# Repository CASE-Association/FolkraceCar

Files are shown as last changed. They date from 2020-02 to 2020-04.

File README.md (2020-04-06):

# CASE Folkrace Car - laZEr

## The 2020 Folkrace car project
 A car developed for the main focus of evaluationg, methos for producing a fun and educational car for the Robot SM Folkrace class.
 These are the main topics:
- Navigation
- Mapping/ localisation
- Electric design
- Cassis design
- Weight optimization

## Project Structure

## Placeholder

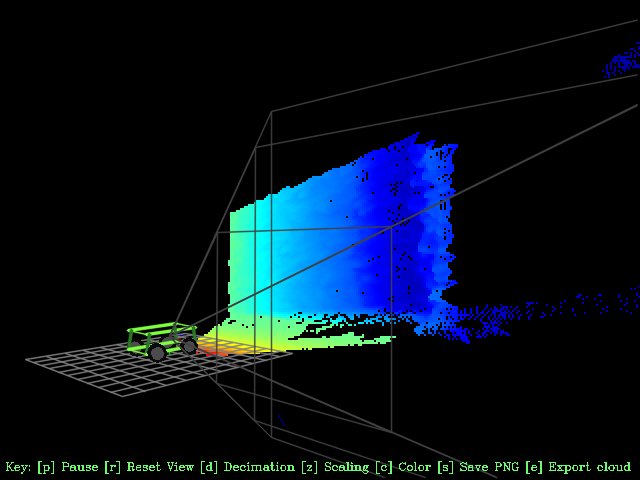
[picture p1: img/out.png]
out


## System overview

## How do you use it?

## How does it work?

## Development

## Contributors

## License

Distributed under the MIT license. See ``LICENSE`` for more information.

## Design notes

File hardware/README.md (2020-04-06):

# Hardware - CASE Folkrace Car

This document describes a general overview of the system hardware used.

### Preliminary rendering of electronics

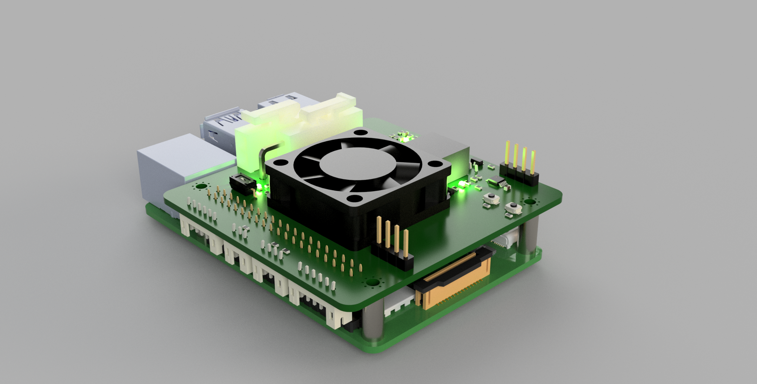
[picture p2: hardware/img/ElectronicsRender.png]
Electronics Render


### Todo hardware
* Add connector for hall effect sensor (should include pull-up)
* Connector for RP4: [Adafruit 2223](https://www.adafruit.com/product/2223) [(from Mouser)](https://www.mouser.se/ProductDetail/Adafruit/2223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)
* Change one TOF connector to angled version - currently interferes with HDMI connectors on RP4.

### Mistakes on REV 1 of PCB

* VBUS bulk decoupling capacitors share single via for ground return path - will probably cause to much inductance. Maybe add cap directly over BATT+ and GND on pcb underside.

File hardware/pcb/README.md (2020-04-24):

## Notes for Folkrace PCB

### Bring up notes for REV 1-2

* eFuse does not work consistently - two have been broken - unclear why

#### Changes for next rev

* Add way to connect external 5V (protection for DC/DC)
* On off for 3V3 (complete rail)
* Move to edge-mounted buttons
* Check real width of screen (38 mm length)
* Reconnect fault LED to not be on when off
* Change to better switch for on/off operation
* Transient protection and possibly reverse current diode for eFuse
* Check if we can change to Molex nano fit connectors (both connectors oriented towards RP conn)
* Add 90 deg connector for start module
* Flip FAN connector so silkscreen looks good

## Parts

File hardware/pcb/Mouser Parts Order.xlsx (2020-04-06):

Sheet: Sheet1
Status | Value | Reference | Qty/board | Order qty | Manufacturer | MPN | DPN | Distributor | Copy paste
 | 100nF X7R > 16 V | C10 | 1 | 10 | Taiyo Yuden | TMK105B7104MV-FR | 963-TMK105B7104MV-FR | Mouser | 963-TMK105B7104MV-FR,Folkrace laZEr,10
 | 10 uF 25 V X7R | C8 C7 C6 C13 C12 | 5 | 10 | Taiyo Yuden | TMK316AB7106KL-T | 963-TMK316AB7106KL-T | Mouser | 963-TMK316AB7106KL-T,Folkrace laZEr,10
 | 22nF X7R > 16 V | C9 | 1 | 10 | Taiyo Yuden | TMF105B7223KVHF | 963-TMF105B7223KVHF | Mouser | 963-TMF105B7223KVHF,Folkrace laZEr,10
 | DRV8874PWPR | IC1 | 1 | 1 | Texas Instruments | DRV8874PWPR | 595-DRV8874PWPR | Mouser | 595-DRV8874PWPR,Folkrace laZEr,1
 | Conn_01x02_Male | J1 J3 | 2 | 4 |  | 39-30-0020 | 538-39-30-0020 | Mouser | 538-39-30-0020,Folkrace laZEr,4
 | Jumper | JP1 JP2 | 2 | 2 |  | TLRZ1JTTD | 660-TLRZ1JTTD | Mouser | 660-TLRZ1JTTD,Folkrace laZEr,2
 | MGSF2N02ELT1G | Q2 | 1 | 2 |  | MGSF2N02ELT1G | 863-MGSF2N02ELT1G | Mouser | 863-MGSF2N02ELT1G,Folkrace laZEr,2
 | SPST | SW1 | 1 | 1 | Omron | A6S-1102-PH | 653-A6S-1102-PH | Mouser | 653-A6S-1102-PH,Folkrace laZEr,1
 | TPS25940x-Q1 | U2 | 1 | 2 | Texas Instruments | TPS25940LQRVCRQ1 | 595-TPS25940LQRVCRQ1 | Mouser | 595-TPS25940LQRVCRQ1,Folkrace laZEr,2
 | ADS1015BQDGSRQ1 | U1 | 1 | 1 | Texas Instruments | ADS1015BQDGSRQ1 | 595-ADS1015BQDGSRQ1 | Mouser | 595-ADS1015BQDGSRQ1,Folkrace laZEr,1
 | Raspberry_Pi Header | J2 | 1 | 1 | Adafruit | Adafruit: 2222 | 485-2222 | Mouser | 485-2222,Folkrace laZEr,1
 | SW_Push | SW2 SW3 | 2 | 2 | Omron Electronics | B3U-1000P-B | 653-B3U-1000P-B | Mouser | 653-B3U-1000P-B,Folkrace laZEr,2
 | M2.5 standoff 11 mm |  | 4 | 4 | Wurth Elektronik | 970110151 | 710-970110151 | Mouser | 710-970110151,Folkrace laZEr,4
 | M2.5 standoff 5+6 mm |  | 4 | 4 | Wurth Elektronik | 971050154 | 710-971050154 | Mouser | 710-971050154,Folkrace laZEr,4
 |  |  | 4 | 4 | Keystone Electronics | 29300 | 534-29300 | Mouser | 534-29300,Folkrace laZEr,4
Recieved | OKL-T_6-W12N-C | U3 | 1 | 0 |  | OKL-T_6-W12N-C | 580-OKL-T/6-W12N-C | Mouser | 580-OKL-T/6-W12N-C,Folkrace laZEr,0

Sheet: kicad csv import
Reference | Quantity | Value | Footprint | Datasheet | DPN | Description | Distributor | MPN | Comments | Manufacturer
C1 C3 C2 C5 C4 | 5 | C | Capacitor_SMD:C_0603_1608Metric | ~
C10 | 1 | 100nF X7R > 16 V | Capacitor_SMD:C_0402_1005Metric | ~ | 963-TMK105B7104MV-FR |  | Mouser | TMK105B7104MV-FR |  | Taiyo Yuden
C11 | 1 | 100nF X7R > 16 V | Capacitor_SMD:C_0201_0603Metric | ~
C8 C7 C6 C13 C12 | 5 | 10 uF 25 V X7R | Capacitor_SMD:C_1206_3216Metric | ~ | 963-TMK316AB7106KL-T |  | Mouser | TMK316AB7106KL-T | Populate if necessary | Taiyo Yuden
C9 | 1 | 22nF X7R > 16 V | Capacitor_SMD:C_0402_1005Metric | ~ | 963-TMF105B7223KVHF |  | Mouser | TMF105B7223KVHF |  | Taiyo Yuden
D2 D1 | 2 | LED RED | LED_SMD:LED_0603_1608Metric | ~
D3 D4 | 2 | LED GREEN | LED_SMD:LED_0603_1608Metric | ~
H1 H2 H5 H6 | 4 | MountingHole | MountingHole:MountingHole_3.2mm_M3_ISO7380 | ~
H3 H7 H4 H8 | 4 | MountingHole_Pad | MountingHole:MountingHole_2.7mm_M2.5_Pad_Via | ~
IC1 | 1 | DRV8874PWPR | DCDC:SOP65P640X120-17N | https://www.ti.com/lit/gpn/DRV8874 | 595-DRV8874PWPR | H-Bridge Motor Driver With Integrated Current Sense and Regulation | Mouser | DRV8874PWPR |  | Texas Instruments
J1 J3 | 2 | Conn_01x02_Male | Connector_Molex:Molex_Mini-Fit_Jr_5569-02A2_2x01_P4.20mm_Horizontal | https://www.molex.com/molex/products/part-detail/pcb_headers/0039300020 | 538-39-30-0020 |  | Mouser | 39-30-0020
J2 | 1 | Raspberry_Pi | Connector_PinSocket_2.54mm:PinSocket_2x20_P2.54mm_Vertical | https://www.raspberrypi.org/documentation/hardware/raspberrypi/schematics/rpi_SCH_3bplus_1p0_reduced.pdf
J4 | 1 | Conn Servo | Connector_JST:JST_PH_B3B-PH-K_1x03_P2.00mm_Vertical | ~
J5 | 1 | Conn Fan | Connector_JST:JST_PH_S2B-PH-K_1x02_P2.00mm_Horizontal | ~
J6 | 1 | Conn Hall Effect | Connector_JST:JST_PH_B4B-PH-K_1x04_P2.00mm_Vertical | ~
J9 J8 J7 | 3 | Conn_01x06_Male | Connector_JST:JST_PH_B6B-PH-K_1x06_P2.00mm_Vertical | ~
JP1 JP2 | 2 | Jumper | Resistor_SMD:R_0603_1608Metric | ~ | 660-TLRZ1JTTD |  | Mouser | TLRZ1JTTD | High current jumper
MODULE1 | 1 | Startmodule | Connector_PinHeader_2.54mm:PinHeader_1x04_P2.54mm_Vertical | ~
MODULE2 | 1 | OLED 128x32 | Connector_PinHeader_2.54mm:PinHeader_1x04_P2.54mm_Vertical | ~
Q1 | 1 | BSS138 | Package_TO_SOT_SMD:SOT-23 | https://www.onsemi.com/pub/Collateral/BSS138-D.PDF
Q2 | 1 | MGSF2N02ELT1G | Package_TO_SOT_SMD:SOT-23 | https://eu.mouser.com/datasheet/2/308/MGSF2N02EL-D-1811613.pdf | 863-MGSF2N02ELT1G |  | Mouser | MGSF2N02ELT1G | High current, low Vgsth nmos
R19 | 1 | 0 | Resistor_SMD:R_0603_1608Metric | ~
R20 | 1 | 1.3k | Resistor_SMD:R_0603_1608Metric | ~
R4 R5 R12 R17 R16 R3 R15 R21 R1 R2 R9 R8 R18 R14 R6 R7 R25 R23 R22 R24 R11 R10 R13 R26 | 24 | R | Resistor_SMD:R_0603_1608Metric | ~
SW1 | 1 | SPST | Button_Switch_SMD:SW_DIP_SPSTx01_Slide_Omron_A6S-110x_W8.9mm_P2.54mm | https://eu.mouser.com/datasheet/2/307/en-a6s-1224092.pdf | 653-A6S-1102-PH |  | Mouser | A6S-1102-PH |  | Omron
SW2 SW3 | 2 | SW_Push | Button_Switch_SMD:SW_SPST_B3U-1000P-B | ~
TP1 | 1 | TestPoint | TestPoint:TestPoint_Pad_D1.5mm | ~
U1 | 1 | ADS1115IDGS | Package_SO:TSSOP-10_3x3mm_P0.5mm | http://www.ti.com/lit/ds/symlink/ads1113.pdf
U2 | 1 | TPS25940x-Q1 | Package_DFN_QFN:QFN-20-1EP_3x4mm_P0.5mm_EP1.65x2.65mm_ThermalVias | http://www.ti.com/lit/ds/symlink/tps25940-q1.pdf | 595-TPS25940LQRVCRQ1 |  | Mouser | TPS25940LQRVCRQ1 | Latching and automotive variant | Texas Instruments
U3 | 1 | OKL-T_6-W12N-C | DCDC:OKL2T6W12PC | https://componentsearchengine.com/Datasheets/1/OKL-T_6-W12N-C.pdf | 580-OKL-T/6-W12N-C | MURATA POWER SOLUTIONS - OKL-T/6-W12N-C - DC/DC CONVERTER, 30W, ADJ OUTPUT | Mouser | OKL-T_6-W12N-C

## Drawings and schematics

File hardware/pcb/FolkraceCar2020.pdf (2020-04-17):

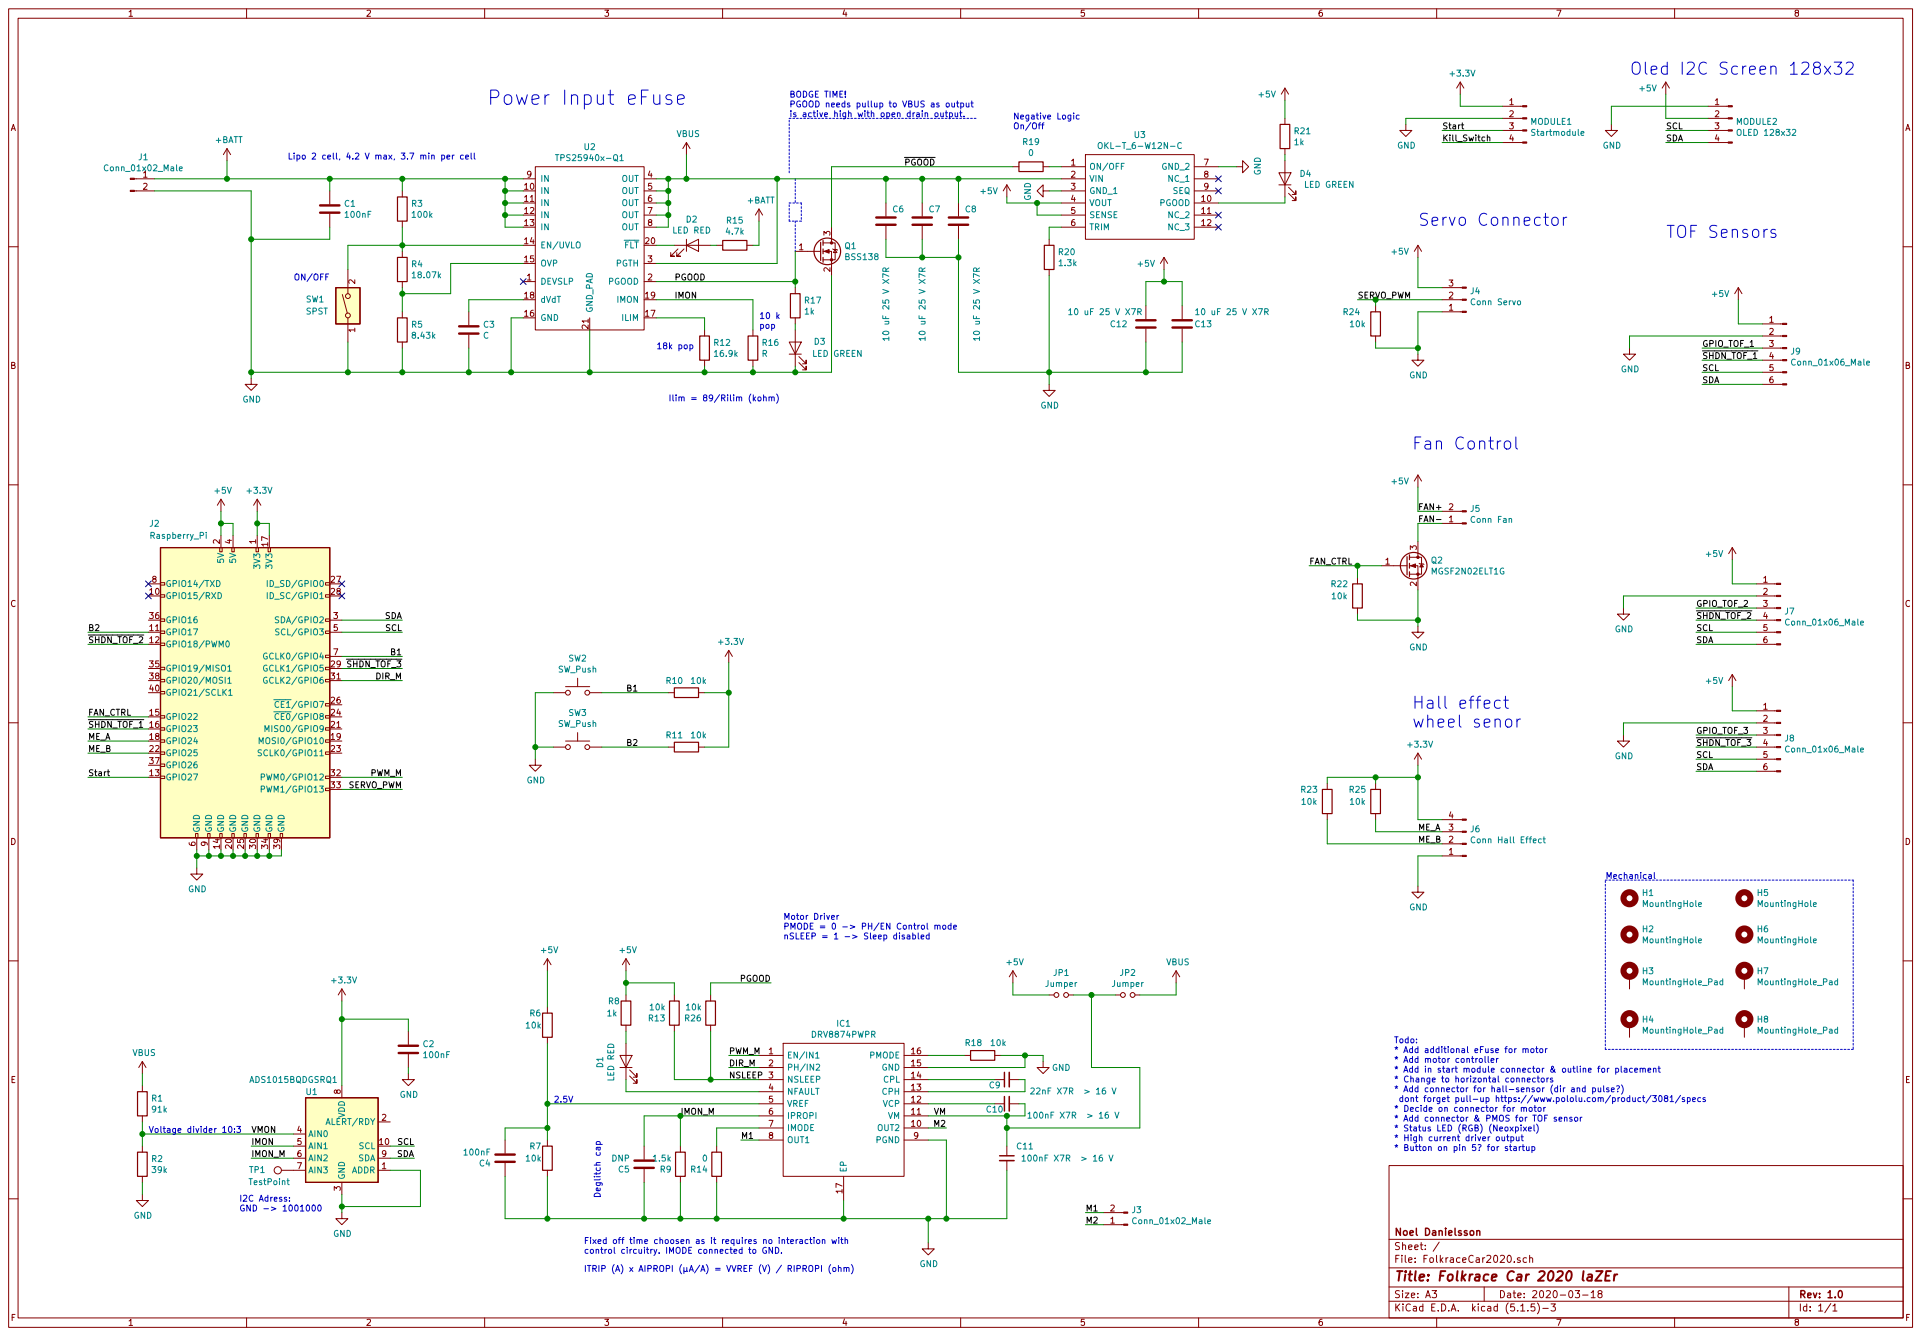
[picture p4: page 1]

Oled I2C Screen 128x32 Deglitch cap

BODGE TIME! PGOOD needs pullup to VBUS as output

is active high with open drain output.

Lipo 2 cell, 4.2 V max, 3.7 min per cell

Motor Driver PMODE = 0 -> PH/EN Control mode

Todo: * Add additional eFuse for motor * Add motor controller * Add in start module connector & outline for placement

* Change to horizontal connectors
* Add connector for hall-sensor (dir and pulse?)
dont forget pull-up https://www.pololu.com/product/3081/specs
* Decide on connector for motor * Add connector & PMOS for TOF sensor * Status LED (RGB) (Neoxpixel)

* High current driver output
* Button on pin 5? for startup

Id: 1/1 Title: Folkrace Car 2020 laZEr File: FolkraceCar2020.sch Sheet: / Noel Danielsson GND

Fixed off time choosen as it requires no interaction with
control circuitry. IMODE connected to GND.
ITRIP (A) x AIPROPI (A/A) = VVREF (V) / RIPROPI (ohm)

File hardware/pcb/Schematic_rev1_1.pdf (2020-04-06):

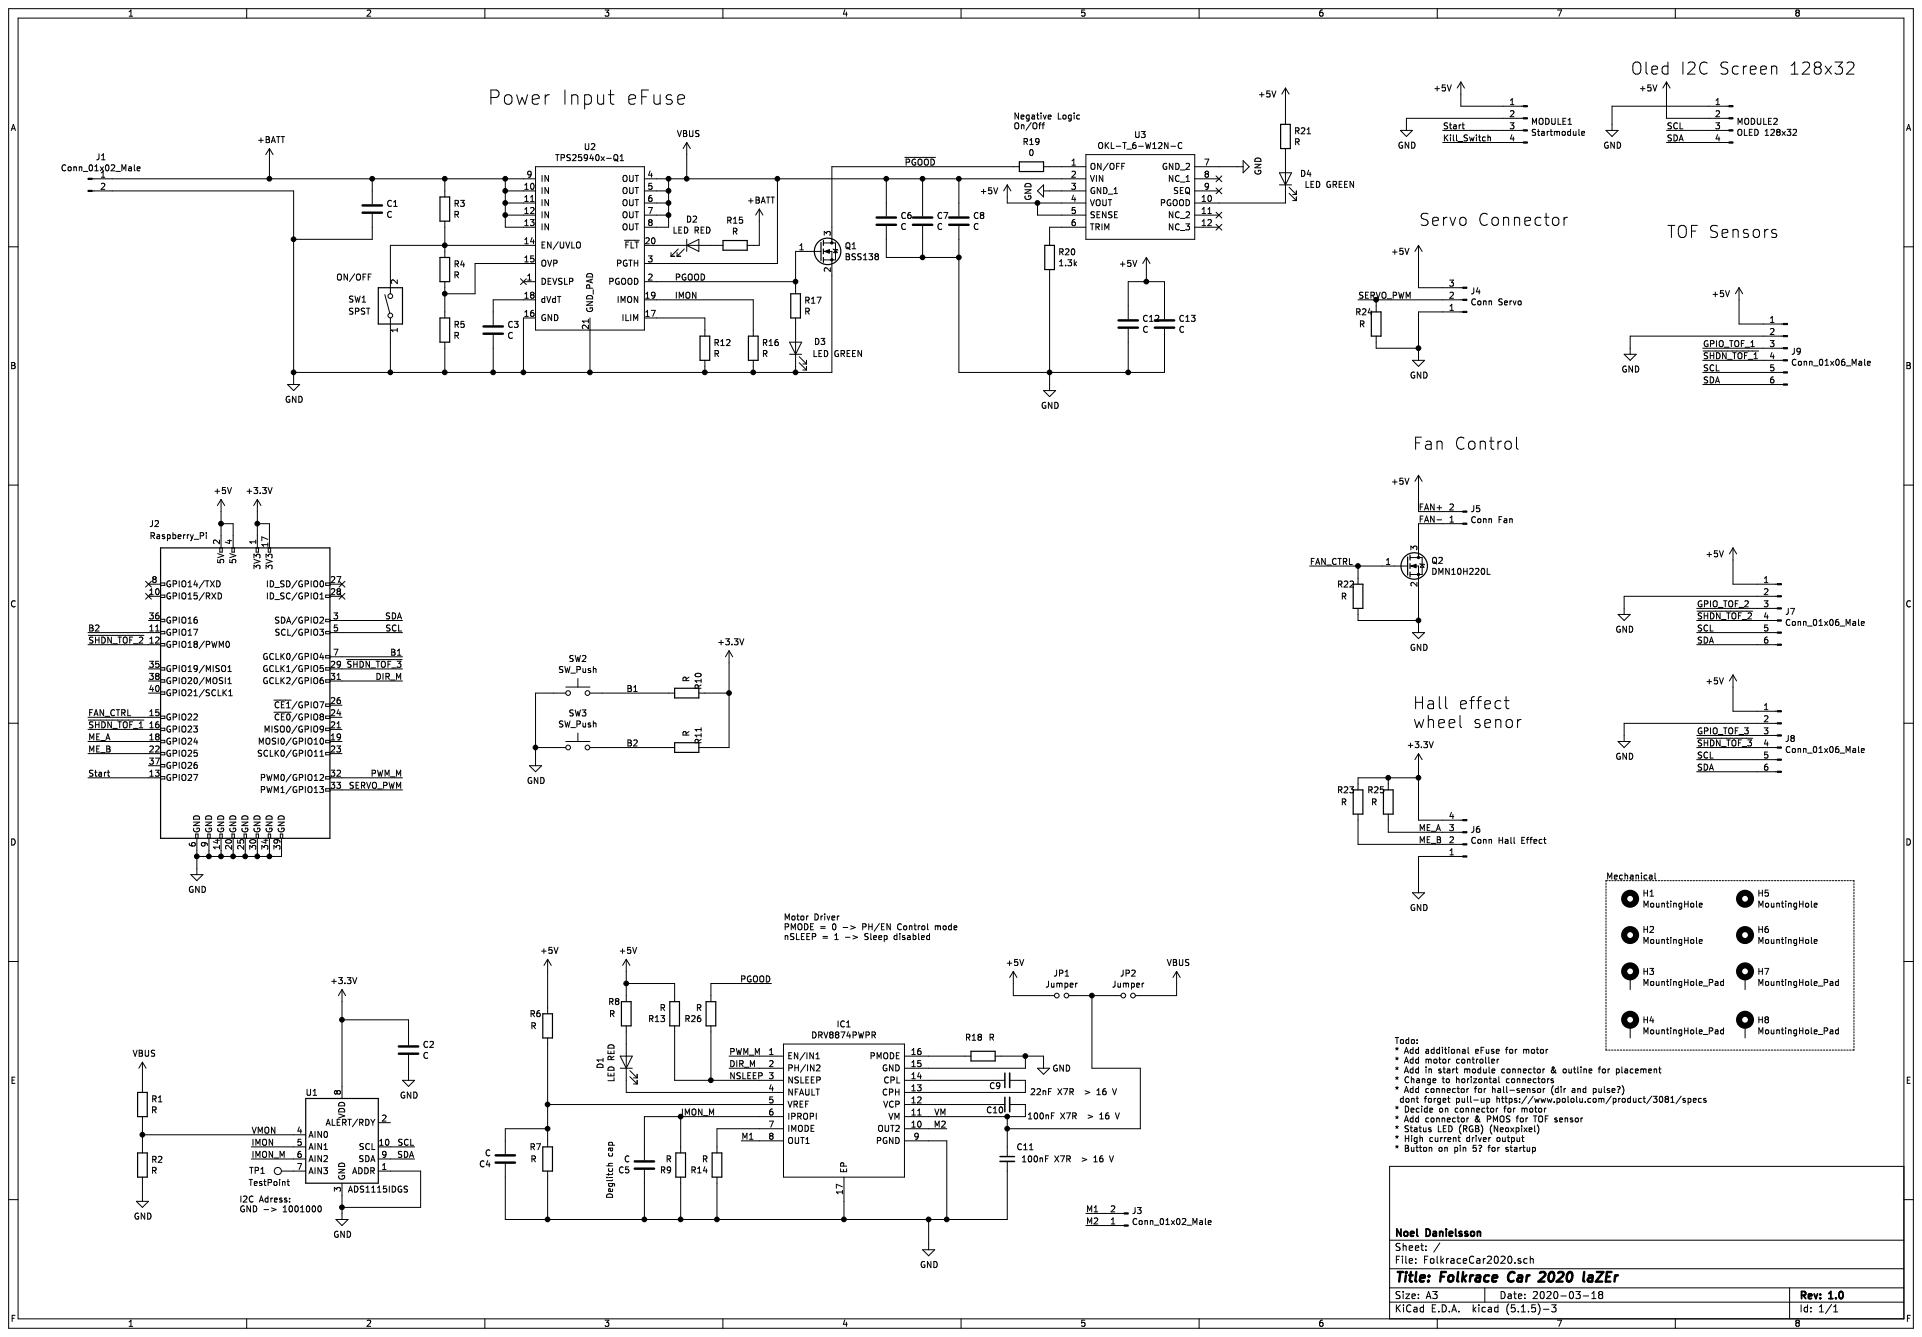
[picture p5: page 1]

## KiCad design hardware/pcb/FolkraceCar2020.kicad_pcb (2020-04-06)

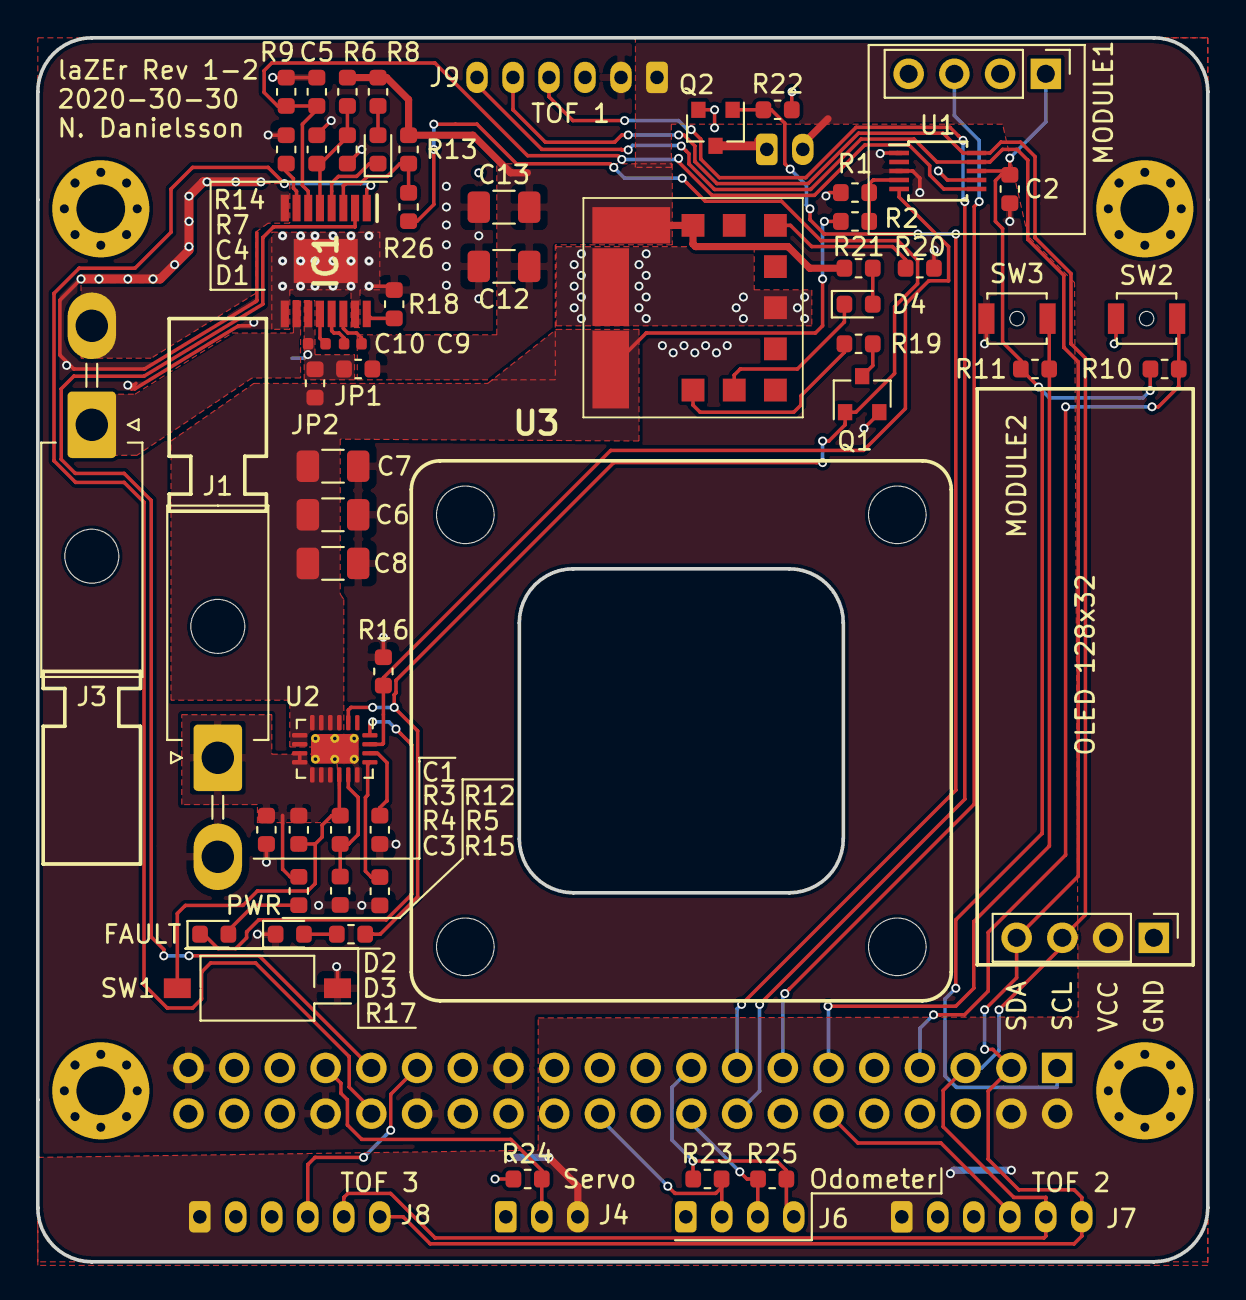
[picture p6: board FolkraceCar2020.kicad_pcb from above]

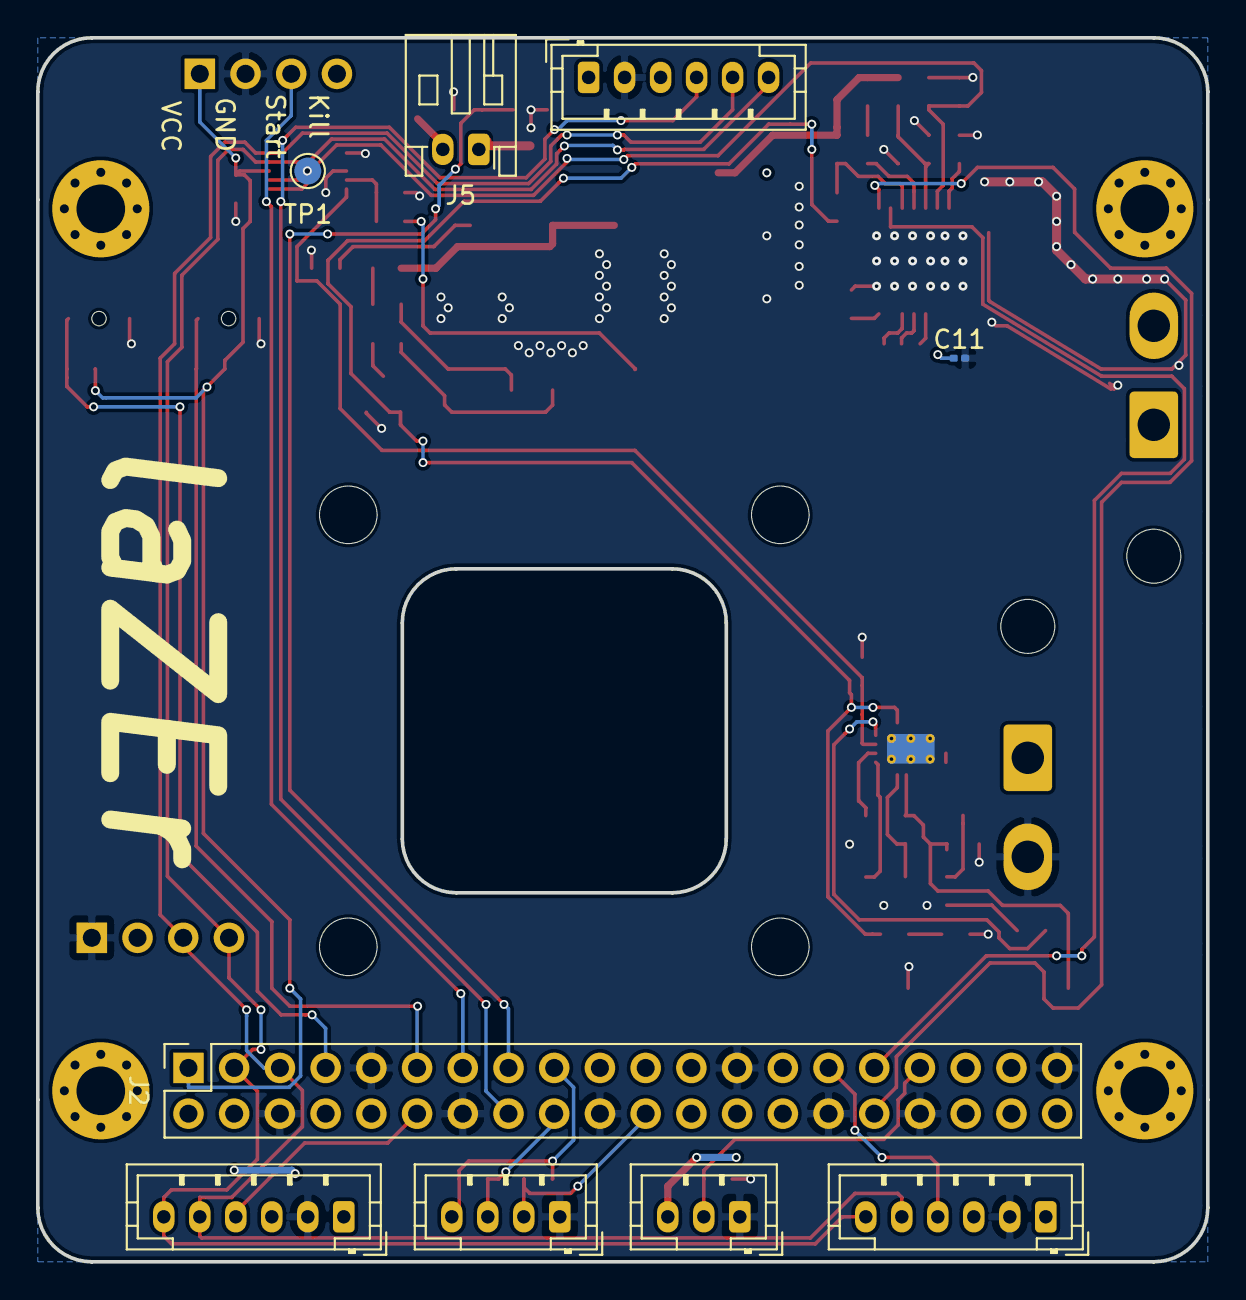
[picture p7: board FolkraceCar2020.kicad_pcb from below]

Board: 2 copper layers, 65.0 x 68.0 mm, 74 parts (9 on the bottom side), 49 nets.

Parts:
C1, C2, C3, C4, C5: C; C_0603_1608Metric
C6, C7, C8, C12, C13: C; C_1206_3216Metric
C9: 22nF X7R > 16 V; C_0402_1005Metric
C10: 100nF X7R > 16 V; C_0402_1005Metric
C11: 100nF X7R > 16 V; C_0201_0603Metric
D1, D2: LED RED; LED_0603_1608Metric
D3, D4: LED GREEN; LED_0603_1608Metric
H1, H2, H5, H6: MountingHole; MountingHole_3.2mm_M3_ISO7380
H3, H4, H7, H8: MountingHole_Pad; MountingHole_2.7mm_M2.5_Pad_Via
IC1: DRV8874PWPR; SOP65P640X120-17N
J1, J3: Conn_01x02_Male; Molex_Mini-Fit_Jr_5569-02A2_2x01_P4.20mm_Horizontal
J2: Raspberry_Pi; PinSocket_2x20_P2.54mm_Vertical
J4: Conn Servo; JST_PH_B3B-PH-K_1x03_P2.00mm_Vertical
J5: Conn Fan; JST_PH_S2B-PH-K_1x02_P2.00mm_Horizontal
J6: Conn Hall Effect; JST_PH_B4B-PH-K_1x04_P2.00mm_Vertical
J7, J8, J9: Conn_01x06_Male; JST_PH_B6B-PH-K_1x06_P2.00mm_Vertical
JP1, JP2: Jumper; R_0603_1608Metric
MODULE1: Startmodule; PinHeader_1x04_P2.54mm_Vertical
MODULE2: OLED 128x32; PinHeader_1x04_P2.54mm_Vertical
Q1: BSS138; SOT-23
Q2: DMN10H220L; SOT-23
R1, R2, R3, R4, R5, R6, R7, R8, R9, R10, R11, R12, R13, R14, R15, R16, R17, R18, R21, R22, R23, R24, R25, R26: R; R_0603_1608Metric
R19: 0; R_0603_1608Metric
R20: 1.3k; R_0603_1608Metric
SW1: SPST; SW_DIP_SPSTx01_Slide_Omron_A6S-110x_W8.9mm_P2.54mm
SW2, SW3: SW_Push; SW_SPST_B3U-1000P-B
TP1: TestPoint; TestPoint_Pad_D1.5mm
U1: ADS1115IDGS; TSSOP-10_3x3mm_P0.5mm
U2: TPS25940x-Q1; QFN-20-1EP_3x4mm_P0.5mm_EP1.65x2.65mm_ThermalVias
U3: OKL-T_6-W12N-C; OKL2T6W12PC

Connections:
+3V3: C2.1, J2.1, J2.17, J6.4, MODULE1.1, R10.1, R11.1, R23.1, R25.1, U1.8
+5V: C12.1, C13.1, J2.2, J2.4, J4.3, J5.2, J7.1, J8.1, J9.1, JP1.1, MODULE2.2, R6.1, R8.1, R13.2, R21.1, U3.4, U3.5
+BATT: C1.1, J1.1, R3.1, R15.1, U2.9, U2.10, U2.11, U2.12, U2.13
/B1: J2.7, R10.2, SW2.2
/B2: J2.11, R11.2, SW3.2
/DIR_M: IC1.2, J2.31
/FAN-: J5.1, Q2.3
/FAN_CTRL: J2.15, Q2.1, R22.1
/IMON: R16.1, U1.5, U2.19
/IMON_M: C5.2, IC1.6, R9.2, U1.6
/M1: IC1.8, J3.2
/M2: IC1.10, J3.1
/ME_A: J2.18, J6.3, R25.2
/ME_B: J2.22, J6.2, R23.2
/NSLEEP: IC1.3, R13.1, R26.1
/PGOOD: Q1.1, R17.1, R26.2, U2.2
/PWM_M: IC1.1, J2.32
/SCL: J2.5, J7.5, J8.5, J9.5, MODULE2.3, U1.10
/SDA: J2.3, J7.6, J8.6, J9.6, MODULE2.4, U1.9
/SERVO_PWM: J2.33, J4.2, R24.1
/Start: J2.13, MODULE1.3
/VM: C10.2, C11.1, IC1.11, JP1.2, JP2.1
/VMON: R1.2, R2.1, U1.4
/~PGOOD: Q1.3, R19.2
/~SHDN_TOF_1: J2.16, J9.4
/~SHDN_TOF_2: J2.12, J7.4
/~SHDN_TOF_3: J2.29, J8.4
GND: C1.2, C2.2, C3.2, C4.1, C5.1, C6.2, C7.2, C8.2, C11.2, C12.2, C13.2, D3.1, IC1.9, IC1.15, IC1.17, J1.2, J2.6, J2.9, J2.14, J2.20, J2.25, J2.30, J2.34, J2.39, J4.1, J6.1, J7.2, J8.2, J9.2, MODULE1.2, MODULE2.1, Q1.2, Q2.2, R2.2, R5.2, R7.2, R9.1, R12.2, R14.1, R16.2, R18.2, R20.2, R22.2, R24.2, SW1.1, SW2.1, SW3.1, U1.1, U1.3, U2.16, U2.21, U3.3, U3.7
unnamed: C3.1, U2.18
unnamed: C4.2, IC1.5, R6.2, R7.1
unnamed: C9.1, IC1.14
unnamed: C9.2, IC1.13
unnamed: C10.1, IC1.12
unnamed: D1.1, IC1.4
unnamed: D1.2, R8.2
unnamed: D2.1, U2.20
unnamed: D2.2, R15.2
unnamed: D3.2, R17.2
unnamed: D4.1, U3.10
unnamed: D4.2, R21.2
unnamed: IC1.7, R14.2
unnamed: IC1.16, R18.1
unnamed: R3.2, R4.1, SW1.2, U2.14
unnamed: R4.2, R5.1, U2.15
unnamed: R12.1, U2.17
unnamed: R19.1, U3.1
unnamed: R20.1, U3.6
unnamed: TP1.1, U1.7
VBUS: C6.1, C7.1, C8.1, JP2.2, R1.1, U2.3, U2.4, U2.5, U2.6, U2.7, U2.8, U3.2

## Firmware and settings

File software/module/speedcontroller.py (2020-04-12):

#!/usr/bin/python3
import multiprocessing as mp
import time
import RPi.GPIO as GPIO
import numpy as np
from software.module.servo import Servo


#  todo
#   convert rpm control to speed control
#   convert speed output to control pwm_pin instead


class SpeedControl:
    def __init__(self, tacho_pin, sample_interval=0.05, kp=500, ki=1000, verbose=False):

        # extrinsics
        self.max_speed = 10  # [m/s]
        self.verbose = verbose
        self.process = None
        self.wheel_diameter = 0.5  # [m]

        # intrinsics
        self._speed = mp.Value('d', 0.0)  # Calculated speed, init speed 0.0 [m/s]
        self._target_speed = mp.Value('d', 0.0)  # the speed that is requested  # [m/s]
        self._power = mp.Value('i', 0)  # the controller power variable, span [-100, 100]%
        self._pin = tacho_pin
        self._wheel_circumference = self.wheel_diameter * np.pi  # [m]
        self._motor_wheel_rpm_ratio = 3  # the ratio between motor axle speed and wheel rpm [Estimation]
        self._run = mp.Value('i', 1)

        # Speed variables
        self._pulse = 0
        self._ppr = 17  # Pulse/ wheel revolution  (est 1pulse/11mm)
        self._rpm = 0
        self._t_last_count = 0  # time of last count

        # PI control values  # todo implement MPC!
        self._kp = kp
        self._ki = ki
        self._sample_interval = sample_interval  # sample time in seconds
        self._windup_guard_val = 150  # Maximum Integration

    @property
    def speed(self):
        """
        The speed retrieved from speed sensors
        :return: current vehicle speed
        """
        return self._speed.value

    @property
    def target_speed(self):
        """
        Set target speed by using the Set_speed funciton
        :return: target speed
        """
        return self._target_speed.value

    @property
    def power(self):
        """
        :return: The controlled power
        """
        return self._power.value

    def start(self):
        # Create speed controller Process
        self.process = mp.Process(target=self.run, args=(self._speed, self._target_speed, self._power,), name='speed_controller')
        # Start speed controller
        self.process.start()

    def end(self):
        if self.process is not None:
            self._run.value = 0
            time.sleep(0.5)
            if self.process.is_alive():
                self.process.terminate()
                if self.verbose:
                    print('SpeedController was terminated')
            elif self.verbose:
                print('SpeedController have ended with exitcode({})'.format(self.process.exitcode))

    def set_speed(self, speed):
        self._target_speed.value = np.clip(speed, -self.max_speed, self.max_speed)

    def _get_speed(self):
        """
        Get how many pulses since last count and divide by time-delta to get w/s.
        Multiply w/s with wheel circumference to the speed in m/s.
        :return: car speed in m/s
        """
        t_now = time.perf_counter()
        delta_t = t_now - self._t_last_count
        p = self._pulse
        if p:  # if pulses > 0, reset counter and timer
            self._t_last_count = t_now
            self._pulse = 0
        else:
            return 0.0
        rps = (p / self._ppr) * delta_t  # wheel rotations per second.
        mps = rps * self._wheel_circumference
        return mps

    def _fault_guard(self, power, timeout=1, safemode_power=10):
        """
        Check if control action have effect. If not, constrain power
        :param power: Requested power
        :param timeout: Constrain if no action before timeout
        :param safemode_power: Max safe power if timed out.
        :return: Safeguarded power.
        """
        if power != 0 and self._rpm == 0 and time.perf_counter() - self._t_last_count > timeout:
            if self.verbose and power != safemode_power:
                pass
                # t = time.strftime("%H:%M:%S", time.gmtime())
                # print('[{}]: Speed Controller in safe mode!\n'
                #      'Power applied but no movement detected!\n'
                #      'Maximum power:{}%'.format(t, safemode_power))
            return np.clip(power, -safemode_power, safemode_power)
        return power

    def _cb_new_pulse(self, channel=None):
        """
        Hall pin transition callback function. Increment pulse each pin transition.
        :return: None
        """
        self._pulse += 1
        # print(channel, self._pulse)

    def run(self, speed, target_speed, power, alpha=0.9):
        """
        Speed controller loop function
        :param speed: Output current speed [multiprocessing.Value]
        :param target_speed: Input controller target speed [multiprocessing.Value]
        :param power: Output controller power
        :param alpha: Smoothing factor of speed reading
        :return: None
        """

        # Setup tachometer pulse callback function
        GPIO.setwarnings(False)
        GPIO.setmode(GPIO.BOARD)
        GPIO.setup(self._pin, GPIO.IN, pull_up_down=GPIO.PUD_UP)  # todo remove when hw pull-up implemented
        GPIO.add_event_detect(self._pin, GPIO.RISING, callback=self._cb_new_pulse)

        # init PI values
        t_last = time.perf_counter()
        self._t_last_count = t_last
        I = 0
        s = 0
        while self._run:
            # PI control
            new_s = self._get_speed()  # Get car speed
            s = alpha * new_s + (1 - alpha) * s  # Smooth speed reading
            speed.value = s
            err = target_speed.value - s
            t_now = time.perf_counter()
            delta_t = t_now - t_last
            # calculate integral part
            I += err * delta_t
            I = np.clip(I, -self._windup_guard_val, self._windup_guard_val)  # prevent integration windup

            #print('E: {}, P: {}, I: {}'.format(round(err, 2),  int(self._kp * err), int(self._ki * I)))

            # Calculate power output and constrain to [-100, 100]%
            pwr = np.clip(int(self._kp * err + self._ki * I), -100, 100)
            pwr = self._fault_guard(pwr, timeout=1, safemode_power=50)  # Check if safe to give power.
            power.value = pwr
            t_last = t_now

            # sleep for reminder of sampling time.
            t_sleep = float(np.clip((2 * self._sample_interval - delta_t), 0, self._sample_interval))
            time.sleep(t_sleep)


def main():
    sc = SpeedControl(tacho_pin=36, verbose=True)
    sc.set_speed(0.03)
    sc.start()
    # init esc
    speed_q = mp.Queue()
    motor = Servo(speed_q, 32)
    motor.start()
    speed_q.put(-1)  # esc unlocking
    time.sleep(0.1)

    t_start = time.perf_counter()

    test_duration = 5  # [s]

    dt = 0.01

    while time.perf_counter() < t_start + test_duration:
        try:
            print('Time: {:2.0f}s,  Speed: {:4.3f}m/s, Power: {}%'
                  .format(round(time.perf_counter(), 0), sc.speed, sc.power))
            time.sleep(dt)
            pwr = np.clip(sc.power, -100, 100)
            speed_q.put(-pwr)  # apply power [inverted]

        except KeyboardInterrupt:
            break
    sc.end()
    motor.end()


if __name__ == '__main__':
    main()

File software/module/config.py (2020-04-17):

"""
Configuration module
"""

# todo change to sys/argument varables

WEBGUI = True
STREAM = False
IMAGERAW = WEBGUI  # generate raw image if Web GUI is used
VERTSRAW = False
FOLKRACE = False

DEBUG = False

frame_width = 424
frame_height = 240
fps = (0, 60)[IMAGERAW]  # disable color if not needed
dfps = 90
FOV = 50  # [deg]
camera_car_offset = [0.01, 0,
                     -2.05]  # The offset from camera to car pivot point. [w h l] [m]
#car_size = [0.2, 0.1, 0.3, 0.05]  # [w h l r]
car_size = [0.2, 0.05, 0.12, 0.05]  # [w h l r]


# I/O CONFIG

FAN = 15
HALL_SENSOR_A = 18
HALL_SENSOR_B = 22
STEER_SERVO = 32
MOTOR_PWM = 33



# Image config
IMG_SIZE = (240, 424, 3)

DECIMATION = 3

# PathFinder
PATH_SMOOTHING = 0.25

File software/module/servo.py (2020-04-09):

#!/usr/bin/python3

import time
from multiprocessing import Process, Queue
import RPi.GPIO as GPIO


class Servo:
    def __init__(self, queue, pin, verbose=False, name='Servo'):
        self.q = queue
        self.servopin = pin
        self.verbose = verbose
        self._name = name

        # intrinsic const, must be set before start!
        self.ang_offset = 0
        self.dc = 0

    def start(self):
        self.p = Process(target=self.run, args=((self.q),))
        #self.q.daemon = True
        self.p.start()

    def end(self):
        self.q.put('END')
        self.p.join(timeout=1)

    def map(self, value):
        """
        Servo running at 50 Hz -> 20 ms per cycle,
        control: high for 1ms to 2ms controls angle
        dutycycle value is from 0 to 100,
        value from controller is -1 to 1
        """
        # at 0 we want to pulse to be 1.5 Ms -> 0.075 duty cycle

        value = ((value + 1) / 2)  # now 0-1
        value = value * (0.1 - 0.05) + 0.05
        # map to 0-100
        return value * 100

    def run(self, queue):
        GPIO.setwarnings(False)
        GPIO.setmode(GPIO.BOARD)
        GPIO.setup(self.servopin, GPIO.OUT)  # step
        self.pwm = GPIO.PWM(self.servopin, 50)

        init_dc = self.map(self.ang_offset/180)
        self.pwm.start(init_dc)  # center output

        while True:
            try:
                #inp = queue.get_nowait()  # get queue input
                inp = queue.get()  # get queue input
                if inp == 'END':
                    queue.close()
                    print('\n\033[92m {} process ended\033[0m'.format(self._name))
                    break
                elif -90 <= inp <= 90:
                    self.dc = self.map(inp/180 + self.ang_offset/180)  # normalize angle and map to dutycycle
                    self.pwm.ChangeDutyCycle(self.dc)  # todo contol values
                    if self.verbose:
                        print("[Servo:", self._name, "] Dutycycle changed to: ",
                              round(inp, 2), "deg, dc= ", round(self.dc, 2))
                else:
                    if inp.any() and self.verbose:
                        print('invalid data:', inp)
            except:
                time.sleep(0.001)
                pass


if __name__ == "__main__":

    servo = Servo(Queue(), pin=32, verbose=True)
    servo.start()
    i = 1
    try:
        while True:
            time.sleep(0.5)

            servo.q.put(i*80 + 10)

            i = -i



    except KeyboardInterrupt:
        pass

    servo.q.put('END')

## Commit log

2020-02-21 add realsense example
    [Box.f3d, Box.step, acrylic_panel.dxf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]
2020-02-23 imp concep ground_plane estimator in path_planner
2020-02-24 migrated image code to MatrixMagic
    [out.ply]
2020-03-07 add strin allocating to print
2020-03-09 servo: initial commit
2020-03-10 add script for enabling pwm
2020-03-10 create Servo class and initial testing
2020-03-11 bugfix servo init frequency
    [servo.py]
2020-03-18 Deleted old folders
    [Box.f3d, Box.step, acrylic_panel.dxf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]
2020-03-18 re-organized folder structure
    [out.ply]
2020-03-18 added hardware and pcb folder
2020-03-18 added kicad project
    [FolkraceCar2020.sch]
2020-03-20 KiCad gitignore file added
2020-03-20 started on schematic design
    [FolkraceCar2020.kicad_pcb, FolkraceCar2020.sch]
2020-03-20 Outline added to pcb layout
    [FolkraceCar2020.kicad_pcb, outline.dxf]
2020-03-22 updated schematic
    [FolkraceCar2020.kicad_pcb, FolkraceCar2020.sch]
2020-03-23 note about hall effect sensor
2020-03-23 init framework for video stream
2020-03-24 added todo in schematic
    [FolkraceCar2020.kicad_pcb, FolkraceCar2020.sch]
2020-03-24 deleted outline
    [outline.dxf]
2020-03-24 added new outline and RP connector
    [FolkraceCar2020.kicad_pcb, FolkraceCar2020.sch]
2020-03-24 added symbol, footprint and 3d model for DRV8874
    [FolkraceCar2020.kicad_pcb, FolkraceCar2020.sch]
2020-03-24 updated footprint
    [FolkraceCar2020.sch]
2020-03-28 bugfix and cleanup
    [out.ply]
2020-03-28 started layout of PCB
    [FolkraceCar2020.kicad_pcb, FolkraceCar2020.sch]
2020-03-28 created fan controller
2020-03-29 extended pcb outline
    [FolkraceCar2020.kicad_pcb]
2020-03-29 worked on pcb layout. Some Schematic def. still to be done
    [FolkraceCar2020.kicad_pcb, FolkraceCar2020.sch]
2020-03-29 Added note about connector problem
2020-03-30 Finished with rev 1
    [FolkraceCar2020.kicad_pcb, FolkraceCar2020.sch]
2020-03-30 fixed 3v3 error
    [FolkraceCar2020.kicad_pcb, FolkraceCar2020.sch]
2020-03-30 added pdf schematic
2020-03-31 pcb rev 1-2
    [FolkraceCar2020.kicad_pcb, FolkraceCar2020.sch]
2020-04-02 updated BOM info in shcematic
    [FolkraceCar2020.sch]
2020-04-02 Started on BOM for Mouser order
    [FolkraceCar2020.sch, Mouser Parts Order.xlsx]
2020-04-05 Updated Mouser order list and added comment to README
    [FolkraceCar2020.sch, Mouser Parts Order.xlsx]
2020-04-09 added get_image function to camera class
2020-04-09 web server can now show camera stream
2020-04-12 concep WebController implemented
    [out.ply]
2020-04-15 added notes and values to components
    [FolkraceCar2020.sch]
2020-04-17 added updated schematic
2020-04-17 initial code for ADC and Oled
